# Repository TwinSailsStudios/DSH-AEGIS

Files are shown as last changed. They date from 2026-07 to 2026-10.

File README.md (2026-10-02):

# DSH-AEGIS


Image of PCB routing and tracing

image of schematic

Image of case + accessories (SD card case, micro sd card case, case cowl, stand, and sd/micro sd card storage)

Image of 3d model

https://github.com/user-attachments/assets/2e60c4a9-2eaf-4800-a794-9d0f289f58ca
Video of 3d model
### UPDATE NOTICE:
alr so i added step/stp files in the hardware folder in a zip file since they were too big for regular uploads (terminal limit is 100mb), i also made the pcb more compact, but the i didnt update the cover image, so you'll have to download the pcb file.

A physical password manager. ESP32-S3, a tiny OLED, six buttons, and an SD card.
Plugs into your computer over USB-C and *types* your passwords for you.

> **Status: designed, not built.** The schematic and PCB are done, the firmware
> is written. I haven't ordered the board yet because I'm paying for this stuff
> myself and PCBs cost money. Everything here is verified in KiCad, not on a
> bench. I'll update this when I can afford to fab it.

## why

I was using the same password on like nine different sites. Which is bad. Every
password manager I looked at wanted me to trust a company with all of it, and I
didn't love that either. So: keep them on an SD card, in my pocket, encrypted.

## what it does

- Locks behind a PIN you enter on the buttons
- Vault is encrypted on the SD card with AES-256
- Types the password straight into the login box over USB
- Can do username → Tab → password to fill a whole form
- Generates strong random passwords
- Auto-locks after 60s if you walk away

The typing thing is the whole point. The ESP32-S3 has **native USB**, so the board
doesn't *pretend* to be a keyboard — your computer genuinely thinks a keyboard got
plugged in. No drivers, no app. Works on any machine you walk up to.

## hardware

| part | what it does |
|---|---|
| ESP32-S3-WROOM-1 | the brain. picked for native USB |
| SSD1306 128x32 OLED | the screen (I2C) |
| 6x tactile switches | the controls |
| microSD module | where the vault lives (SPI) |
| USB-C receptacle | power + keyboard |
| AMS1117-3.3 | 5V → 3.3V |
| 2x 5.1K resistors | CC pins, so USB-C actually gives you power |

## pinout

| pin | goes to |
|---|---|
| IO0–IO5 | RECORD, SAVE, PLAY, SCROLL-L, SELECT, SCROLL-R |
| IO6 / IO7 | OLED SCL / SDA |
| IO35–IO38 | SD CS / MOSI / SCK / MISO |

**Heads up on IO35–37.** On an ESP32-S3 module with **octal (R8) PSRAM**, those
three pins are wired to the PSRAM die internally and you can't use them as GPIO.
This board only works with a **no-PSRAM or quad-PSRAM** module. If you build it,
check the part number, and set **PSRAM: Disabled** in the Arduino IDE — leave it
on OPI and the chip claims those pins at boot, before your code runs, and the SD
card silently never mounts.

## how you'd use it

Enter your PIN. Scroll to the login you want with the arrow buttons. Click into
whatever password box you're filling out on your computer. Hit **PLAY**. Done.

**SELECT** opens a menu with more options: type just the password, type
username+Tab+password, show the password on screen, or delete it.

Adding a new entry is the weak spot right now — you press **RECORD** and it hands
off to the serial monitor, where you send `label⇥username⇥password`. A password
manager that needs a computer to set up is a bit embarrassing and I want to fix
it. (Put `*` as the password and it generates one for you.)

Then hit **SAVE** to encrypt it and write it to the card.

## the crypto

Boring on purpose. Your PIN goes through PBKDF2-HMAC-SHA256 (60,000 rounds, random
salt) to turn 4 digits into a real key. Vault is AES-256-CBC. There's an HMAC over
the ciphertext, so a wrong PIN fails the check and the device never even attempts
to decrypt. Salt and IV are fresh every save.

I did not invent any of this. Inventing your own crypto is how you become a
cautionary example in someone's blog post.

## build it yourself

Firmware is in `firmware/`. You need the **U8g2** library; everything else ships
with the ESP32 Arduino core.

Board settings:
- Board: ESP32S3 Dev Module
- USB CDC On Boot: **Enabled**
- USB Mode: **USB-OTG (TinyUSB)**
- PSRAM: **Disabled** (see the IO35 warning above)

KiCad project is in `hardware/`.

## what's not done

- **Never physically built.** Simulated and verified in KiCad only.
- A 4-digit PIN is 10,000 combinations. The PBKDF2 rounds slow an attacker down a
  lot but it's not amazing if someone steals the card and is patient.
- No lockout after repeated wrong guesses.
- Can't add entries on the device, needs serial.
- No way to change your PIN without wiping everything.
- Case is modelled in Tinkercad but not printed.

## AI use
I used gemini to help with some kicad features and trying to debug a probelm with exporting my 3d model of my pcb
I used Claude to help write the firmware and to talk through design decisions
(pin conflicts, how to structure the vault encryption). The schematic, PCB layout, 
3D model, and this README are mine. the firmware, im not gonna act like i wrote it from scratch, it was more like using claude to frankenstien my code togetehr into a working firmware, since i haventbuilt ts irl yet, if any of yall try PLEASE lmk if theres any code problems, thx:)

EDIT: I also gave claude access to organize all the files

## license

MIT. do whatever.

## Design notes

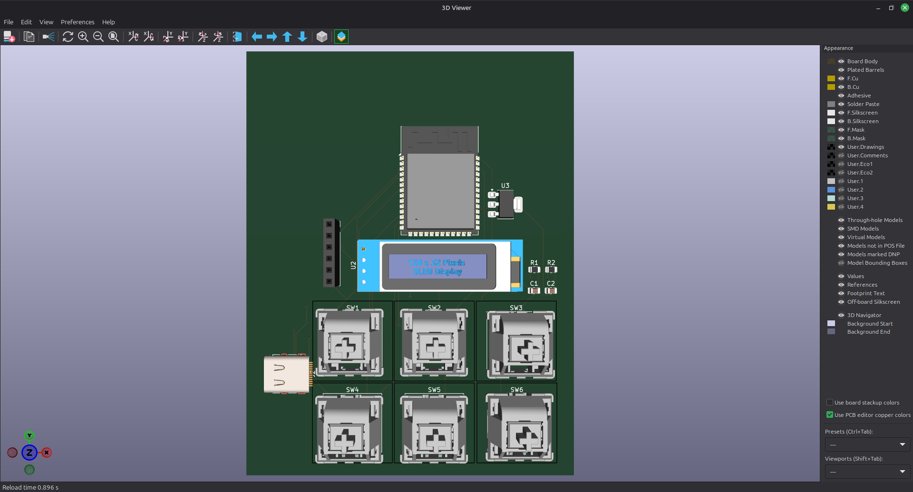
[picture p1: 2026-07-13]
assets/1783965913131_image.png

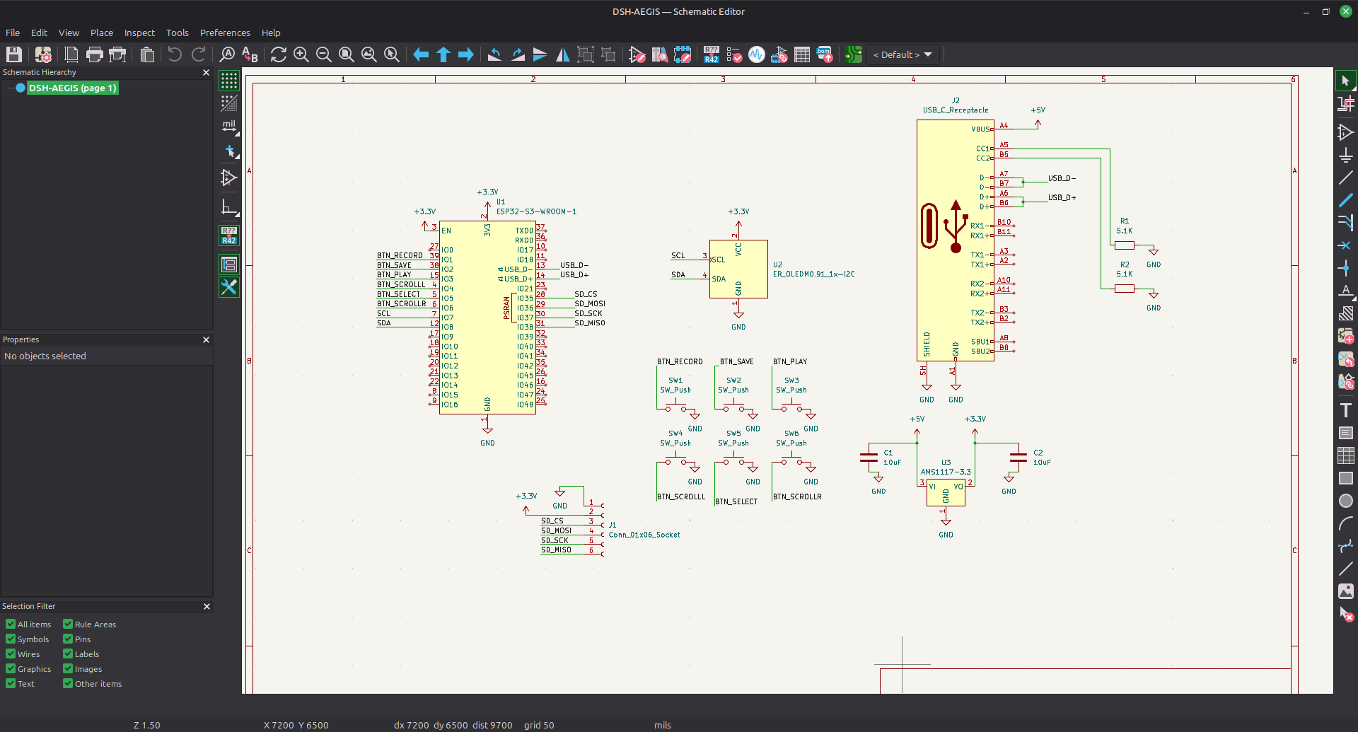
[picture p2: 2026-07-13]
assets/1783965924997_image.png

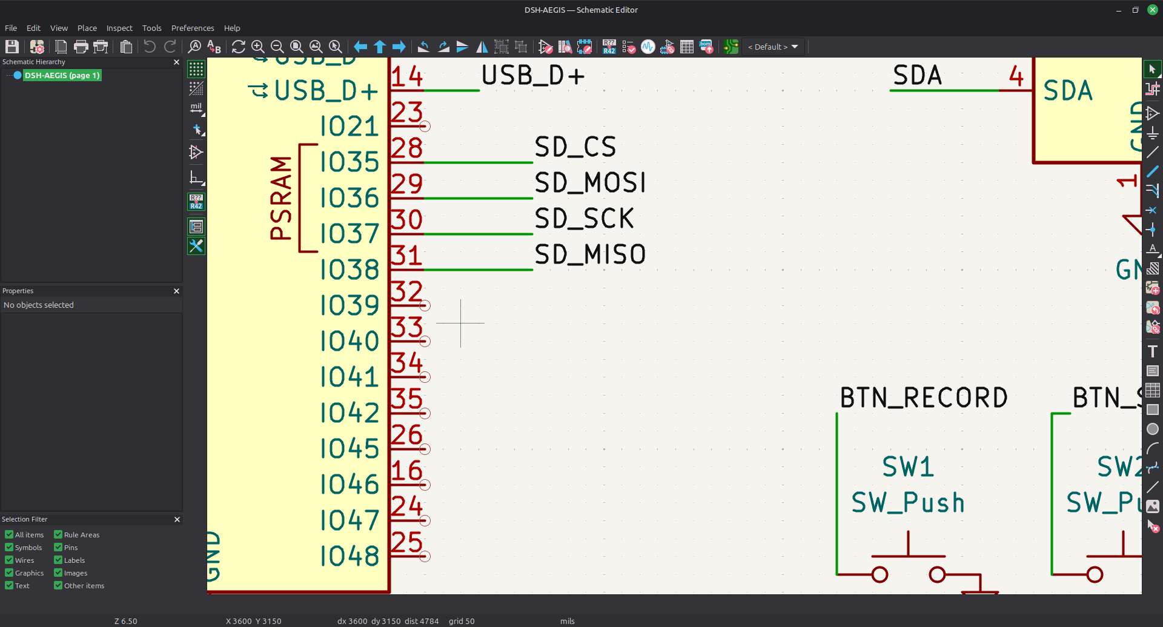
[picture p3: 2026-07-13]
assets/1783966510751_image.png

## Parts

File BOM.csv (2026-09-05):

Item / Component Name | Description / Purpose | Qty | Price (USD) | Total Cost (USD) | Buying Link
1x ESP32-S3-WROOM-1 (N16R8) | Main MCU module - WiFi/BLE USB HID drives OLED + SD vault | 1 | 3.40 | 3.40 | https://www.lcsc.com/product-detail/C2913202.html
1x 0.96" I2C OLED (SSD1306 4-pin) | 128x64 status/UI display I2C addr 0x3C | 1 | 17.50 | 17.50 | https://www.adafruit.com/product/326
1x AMS1117-3.3 (SOT-223) | 3.3V LDO regulator steps 5V USB rail to 3.3V | 1 | 0.10 | 0.10 | https://www.lcsc.com/product-detail/C6186.html
2x 10uF ceramic capacitor | LDO input/output bulk decoupling | 2 | 0.03 | 0.06 | https://www.lcsc.com/search?q=10uF%200603%2025V%20X7R
1x 1uF ceramic capacitor | EN-pin RC power-on delay | 1 | 0.02 | 0.02 | https://www.lcsc.com/search?q=1uF%200603%2050V%20X7R
1x USB-C Receptacle (16-pin) | USB 2.0 power + data TYPE-C-31-M-12 | 1 | 0.30 | 0.30 | https://www.lcsc.com/product-detail/C165948.html
1x 1x6 Pin Header Socket (2.54mm) | MicroSD SPI breakout connector | 1 | 0.15 | 0.15 | https://www.lcsc.com/search?q=female%20header%201x6%202.54mm
6x Cherry MX Keyswitch | Tactile push buttons MX1A-11NN | 6 | 1.25 | 7.50 | https://www.digikey.com/en/products/detail/cherry-americas-llc/MX1A-11NN/91136
2x 5.1k resistor | USB-C CC1/CC2 pulldowns UFP sink detection | 2 | 0.01 | 0.02 | https://www.lcsc.com/search?q=5.1k%200603%20resistor
1x 10k resistor | EN-pin pull-up | 1 | 0.01 | 0.01 | https://www.lcsc.com/search?q=10k%200603%20resistor
 |  |  | GRAND TOTAL | 29.06

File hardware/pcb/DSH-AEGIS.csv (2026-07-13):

Reference | Qty | Value | DNP | Exclude from BOM | Exclude from Board | Footprint | Datasheet
C1,C2 | 2 | 10uF |  |  |  | Capacitor_SMD:C_0805_2012Metric
J1 | 1 | Conn_01x06_Socket |  |  |  | Connector_PinSocket_2.54mm:PinSocket_1x06_P2.54mm_Vertical
J2 | 1 | USB_C_Receptacle |  |  |  | Connector_USB:USB_C_Receptacle_XKB_U262-16XN-4BVC11 | https://www.usb.org/sites/default/files/documents/usb_type-c.zip
R1,R2 | 2 | 5.1K |  |  |  | Resistor_SMD:R_0805_2012Metric
SW1,SW2,SW3,SW4,SW5,SW6 | 6 | SW_Push |  |  |  | Button_Switch_Keyboard:SW_Cherry_MX_1.00u_PCB
U1 | 1 | ESP32-S3-WROOM-1 |  |  |  | RF_Module:ESP32-S3-WROOM-1 | https://www.espressif.com/sites/default/files/documentation/esp32-s3-wroom-1_wroom-1u_datasheet_en.pdf
U2 | 1 | ER_OLEDM0.91_1x-I2C |  |  |  | Display:ER_OLEDM0.91_1x-I2C | https://www.buydisplay.com/download/manual/ER-OLEDM0.91-1_Datasheet.pdf
U3 | 1 | AMS1117-3.3 |  |  |  | Package_TO_SOT_SMD:SOT-223-3_TabPin2 | http://www.advanced-monolithic.com/pdf/ds1117.pdf

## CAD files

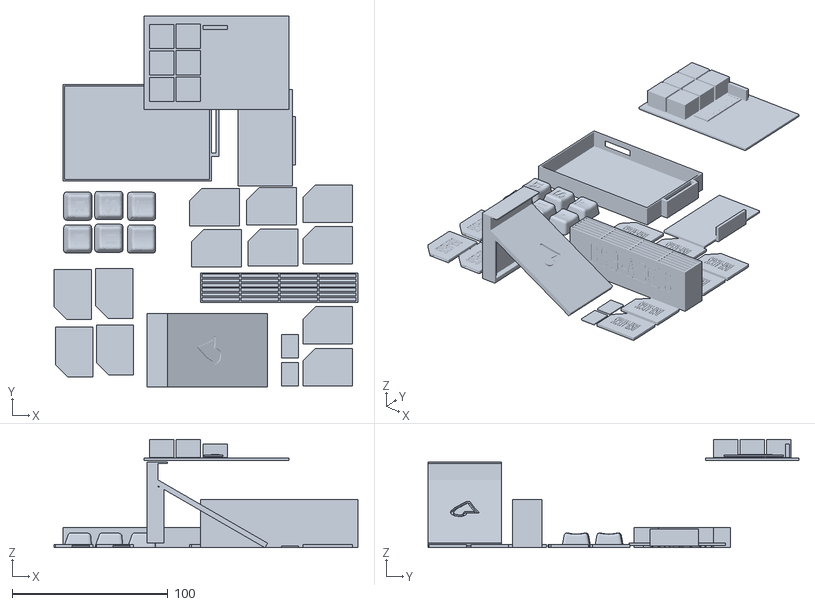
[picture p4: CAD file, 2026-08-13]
hardware/cad/DSH-AEGIS CASE VER 1.stl
194.8 x 238.0 x 69.6

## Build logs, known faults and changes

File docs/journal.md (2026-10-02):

---
title: "DSH-AEGIS"
author: "Pratik Dash (TwinSailsStudios)"
description: "A physical password manager. ESP32-S3, OLED, six buttons, SD card. Plugs in over USB-C and types your passwords for you."
created_at: "2026-06-24"
---

Quick note before anything: this is a design log, not a build log. I did the schematic, the PCB, the case, and the firmware, but I have not ordered the board. PCBs cost money and I'm paying for my own hobbies. So none of this has been flashed or tested on real hardware, it's all verified in KiCad, but it might not work if you do try to build it. HOLY IM SO DONE WITH MY LAPTOP, IT TURNED OFF WHILE I WAS ADDING MY LAPSE LINKS AND I LOST MY PROGROESS. IT DIDNT EVEN RUN OUTTA POWER.

# Day 1 - Starting the schematic - June 24th - 5 Hours

I've decided to build a physical password manager. Little handheld thing, screen, six buttons, SD card in the back, plugs into your computer over USB-C and types your passwords for you. I got tired of using the same password on like nine different sites which is objectively terrible.

I've done PCB stuff before but nothing with a chip this big, so this is a step up for me.

First thing I had to decide was the MCU, and I went with the ESP32-S3. The big reason is native USB. That means the board doesn't pretend to be a keyboard, your computer genuinely thinks a keyboard got plugged in. No drivers, no app, works on any machine you walk up to. If I used a normal ESP32 I'd need a whole separate USB chip and it gets uglier and more expensive.

Opened KiCad, dropped the S3 symbol in, and immediately felt out of my depth. This chip has an absurd number of pins. Spent most of today just reading the symbol figuring out which ones I'm even allowed to touch.

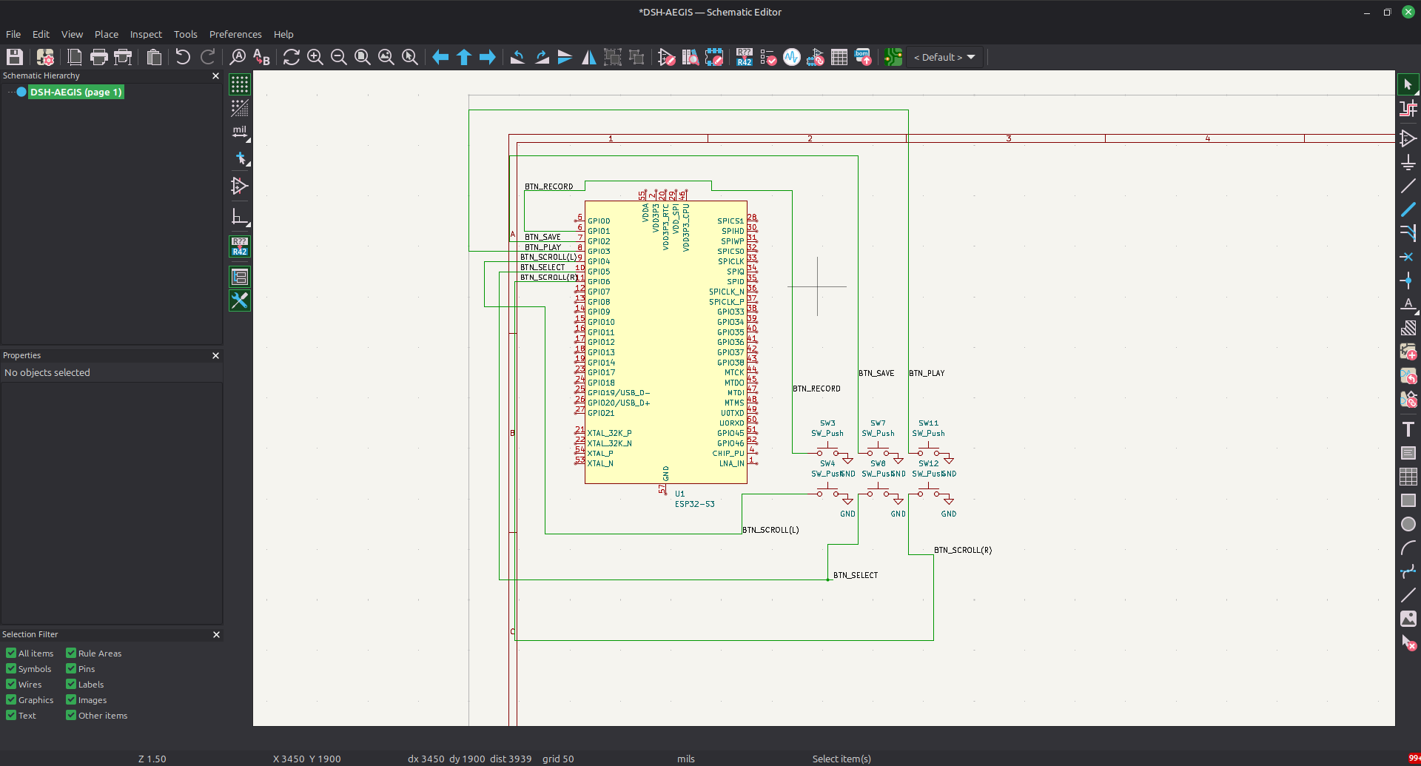
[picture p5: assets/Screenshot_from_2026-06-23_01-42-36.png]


Then I did the six buttons. RECORD, SAVE, PLAY, SCROLL LEFT, SELECT, SCROLL RIGHT. Each one is just a GPIO on one leg and ground on the other, that's it. No pull-up resistors needed because the ESP32 has them built in and I turn them on in software. Six fewer parts to buy.

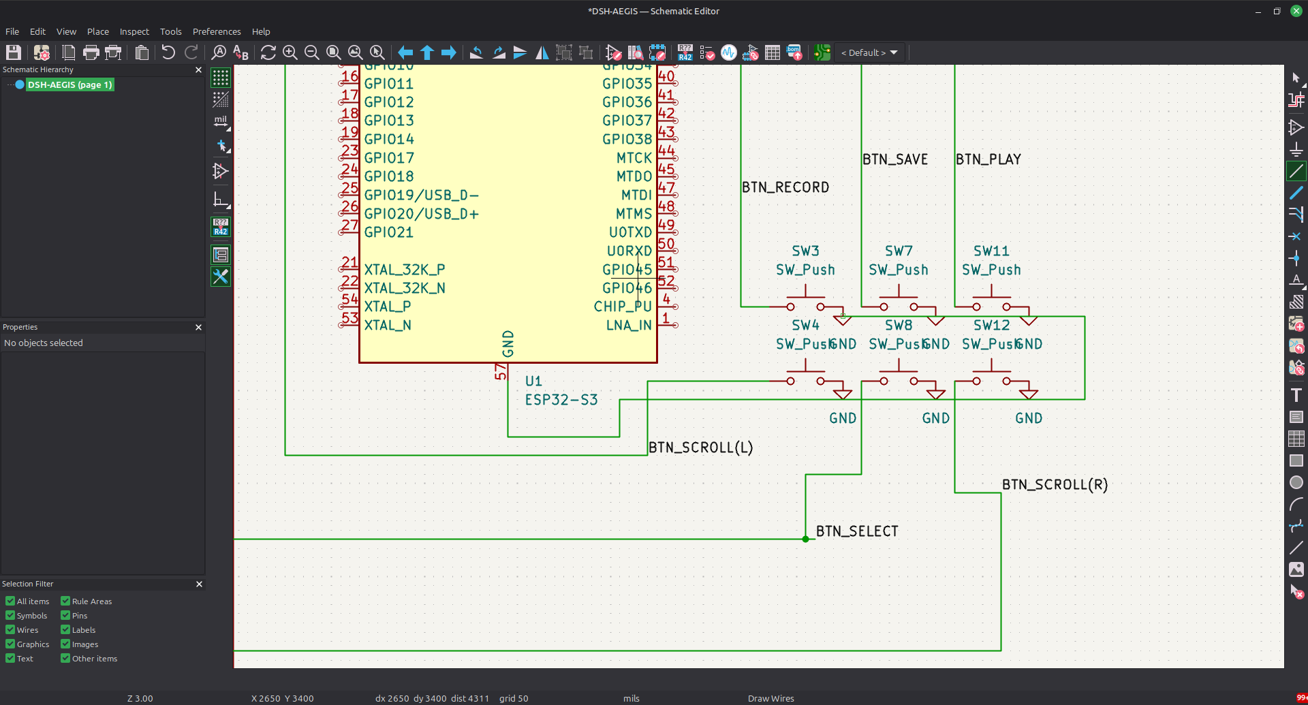
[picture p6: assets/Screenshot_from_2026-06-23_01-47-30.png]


The wires got messy but KiCad only cares that the connections are right, not that it looks nice.

Lapse: [yo MURDER my laptop]

**Total time spent: 5h**

# Day 2 - Rest of the schematic + footprints - June 25th - 6 Hours

Added everything else today:

* the OLED, which is I2C so only two wires, SCL and SDA
* the SD card socket, SPI, four wires
* USB-C receptacle
* AMS1117-3.3 to drop 5V down to 3.3V
* two 5.1K resistors on the CC pins

Those resistors are important and I almost didn't put them in. Without them the USB-C port has no way to tell your laptop "hey I'm a device, give me power" and the board just doesn't turn on. I only knew about this because I read like four forum threads of people asking why their USB-C board was dead and the answer was always the CC resistors.



Then footprints, which nobody warns you about. A schematic symbol is basically a cartoon, it doesn't know how big the real part actually is. So you have to go through every single component and tell KiCad which exact physical shape it is in real life.

15 components, one at a time, out of a list of 7,447 footprints.

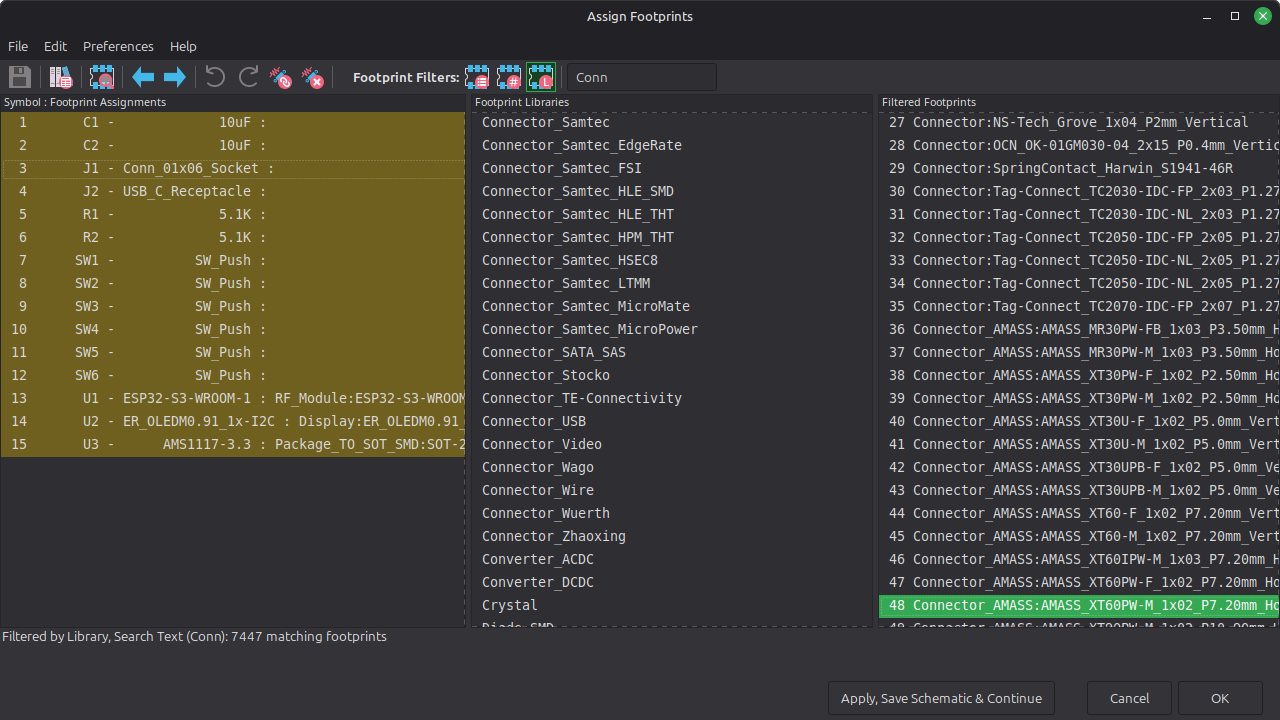
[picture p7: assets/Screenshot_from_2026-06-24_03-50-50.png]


I have now seen every connector ever manufactured.

Lapse: ["yeah add a lapse section, it'll be such a good idea!"]

**Total time spent: 6h**

# Day 3 - PCB layout, the long day - June 26th - 8 Hours

Biggest day by a mile. Today the schematic became an actual board.

When you first push everything into the PCB editor it just dumps all the parts in a pile with a horrifying spiderweb of white lines showing what needs to connect to what. It looks impossible. It's not, it just takes eight hours.

The layout I went with is six buttons in a 2x3 grid at the bottom like a keypad, OLED sitting right above them, ESP32 up top, USB-C on the left edge so the cable comes out the side instead of jabbing into your hand.

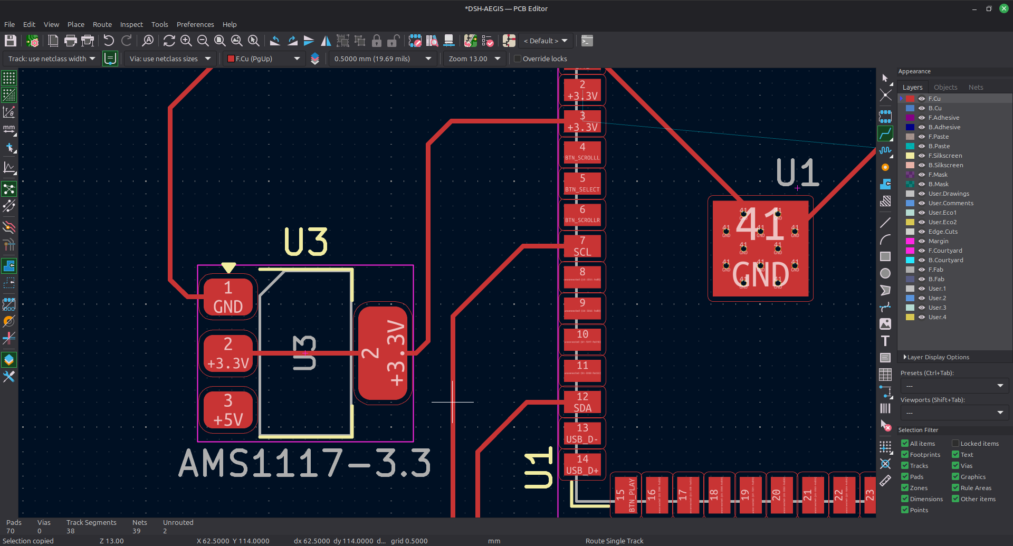
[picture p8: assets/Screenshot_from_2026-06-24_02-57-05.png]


Learned the annoying way that the ESP32 module has an antenna on it and you can't run copper underneath an antenna or the wifi gets worse. So there's this big hatched keep-out zone across the top of my board that I'm not allowed to route through. Had to redo a few traces once I realized.

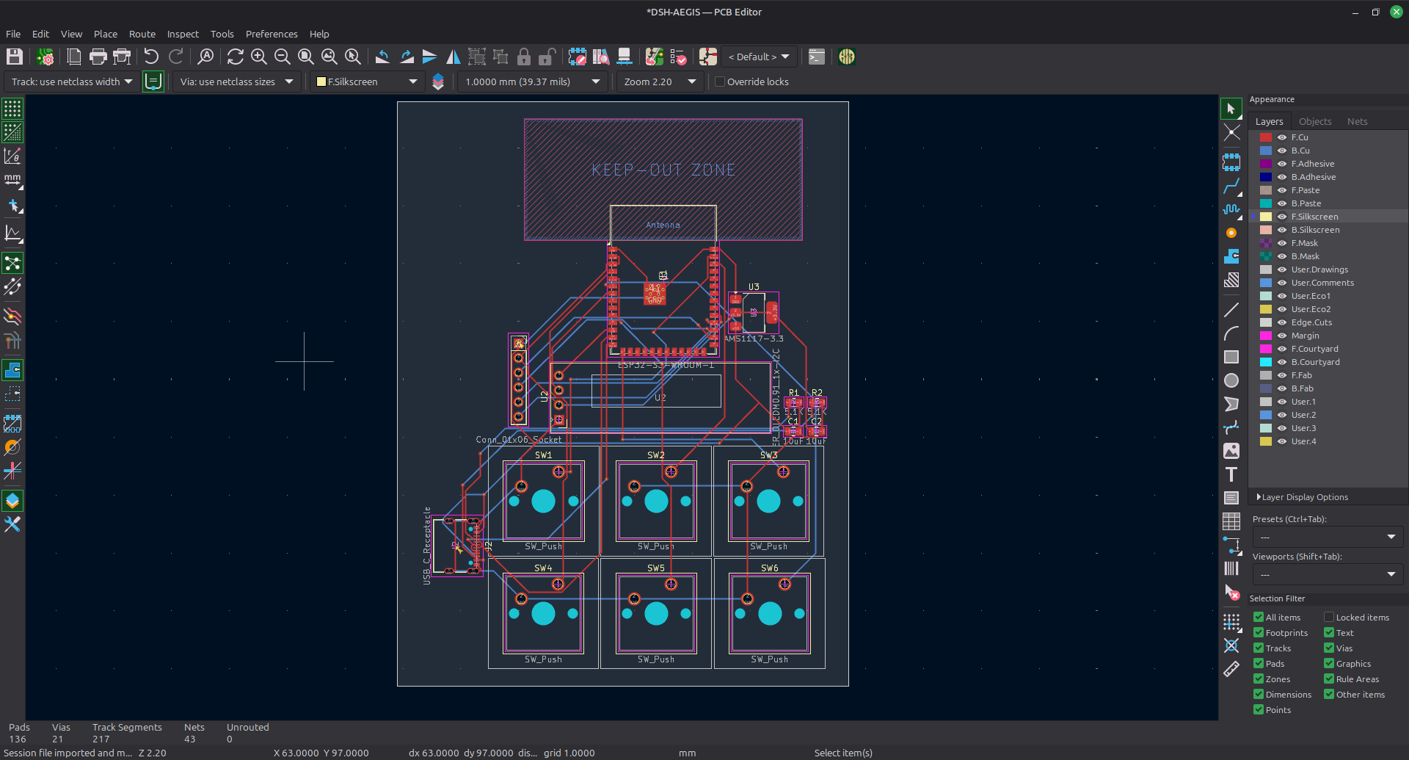
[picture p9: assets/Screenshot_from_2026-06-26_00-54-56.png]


Ended at 217 track segments, 21 vias, 43 nets, 0 unrouted. That last number is the one that actually matters and I looked at it for a while.

Did not move from this chair all day.

Lapse: [waaaaaaaaaaaaaaaaah]

**Total time spent: 8h**

# Day 4 - Silkscreen, and catching a pin conflict that would've cost me a board - June 27th - 4 Hours

Easy day mostly. Silkscreen is the white printing on a PCB and it costs literally nothing extra, the fab prints it either way, so obviously I put a heart on the back, my name, the project name, and some Kanye lyrics down the side.

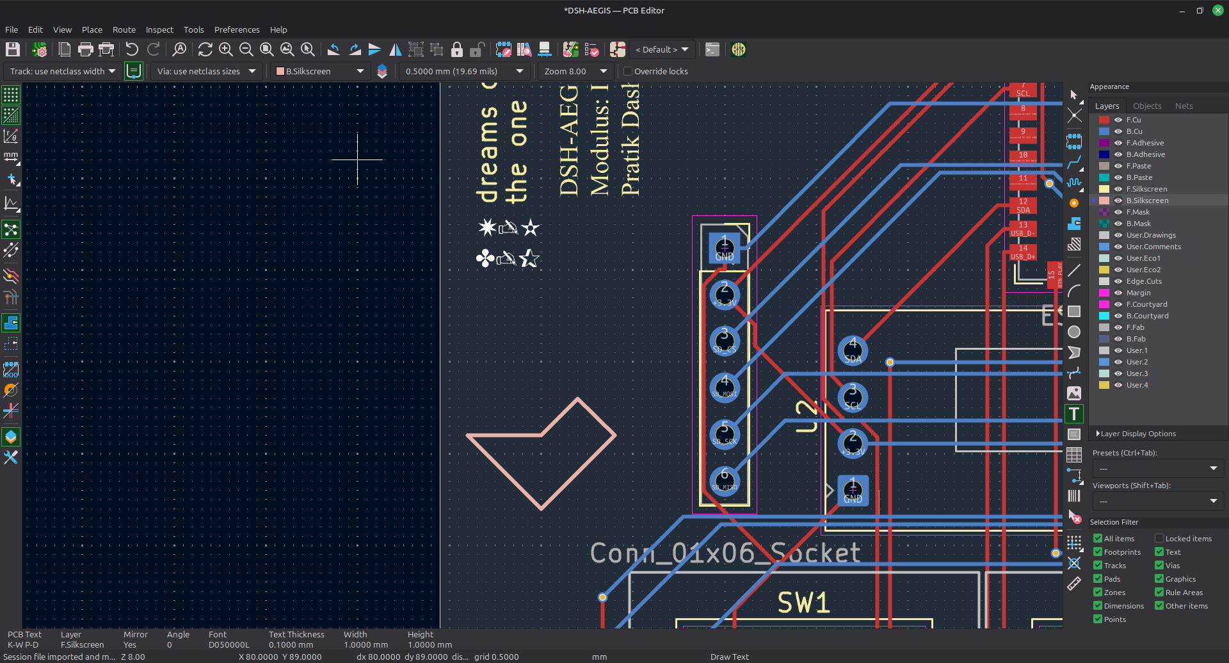
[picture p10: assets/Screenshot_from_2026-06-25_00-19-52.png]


Then while I was double checking my pin assignments against the datasheet before calling the board done, I found something that would've ruined the entire PCB order.

My SD card is on IO35, IO36, IO37 and IO38. On an ESP32-S3 module with octal (R8) PSRAM, IO35 through 37 are wired internally to the PSRAM chip. You physically cannot use them as GPIO. The KiCad symbol even brackets those three pins and literally labels them PSRAM, and I had been staring at that label for three days without it registering.

So this board only works with a module that has no PSRAM or quad PSRAM. And in the firmware, PSRAM has to be set to Disabled, because if the ESP32 thinks it has OPI PSRAM it grabs those pins at boot before my code even runs, and the SD card would just silently never mount.

I would have had zero clue why. I'd have gotten the board back, soldered the whole thing, and spent a weekend blaming my solder joints. Very glad I caught this on a screen and not on a desk. Put a big comment about it at the top of the firmware.

Then opened the 3D viewer to see what it'd look like when it's real, and honestly it looks like a product.

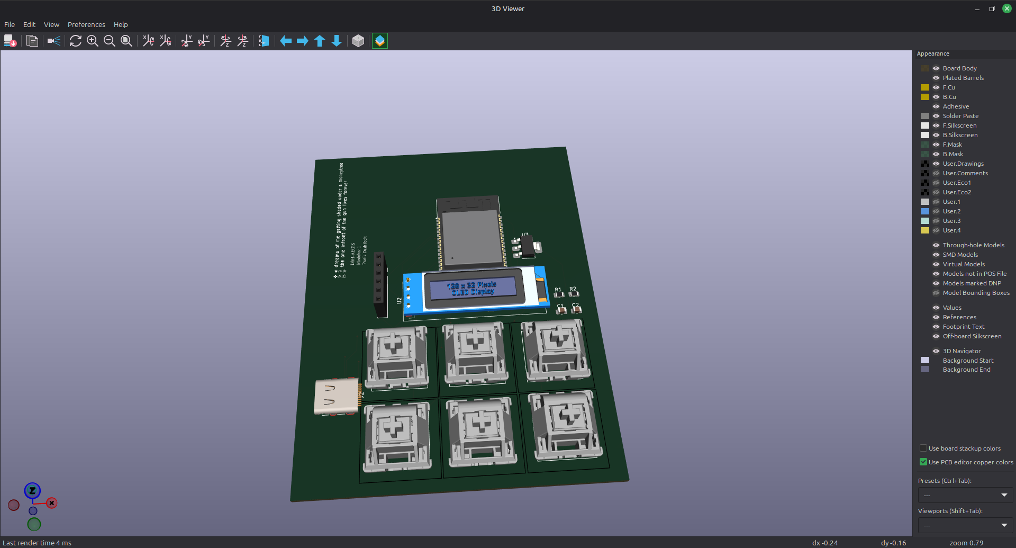
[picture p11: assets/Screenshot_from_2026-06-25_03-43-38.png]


Lapse: [TIMWANMNIHAC]

**Total time spent: 4h**

# Day 5 - Case in Tinkercad - June 28th - 5 Hours

A bare PCB in your pocket is a short circuit waiting to happen so it needs a case.

I used Tinkercad. I know. But I need a box with holes in it and Tinkercad makes a box with holes in it in fifteen minutes, and Fusion 360 makes me want to lie down. I'll learn Fusion eventually.

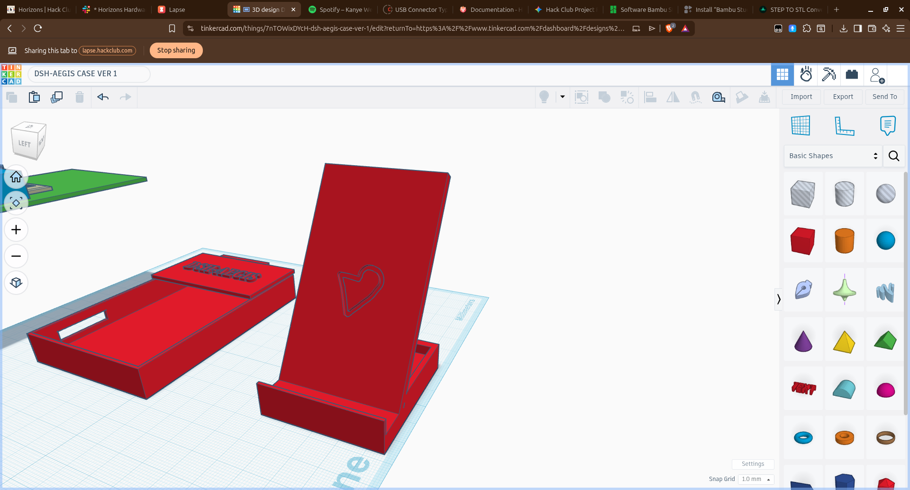
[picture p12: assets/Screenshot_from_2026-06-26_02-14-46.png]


Version 1 is a bottom tray the PCB drops into, a lid with a window cut out for the OLED, six button caps, a front piece with the heart on it, and cutouts for the USB-C port on the side and the SD card slot.

Then I laid everything out flat to check it'd actually print, and mostly to check the button caps weren't so tiny they'd fly off the print bed and disappear into the carpet forever.

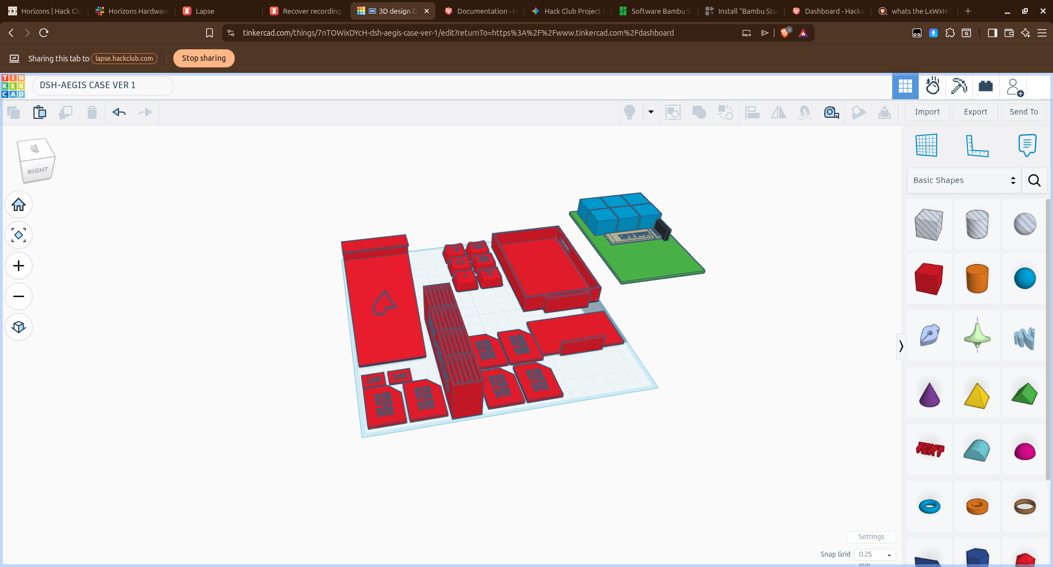
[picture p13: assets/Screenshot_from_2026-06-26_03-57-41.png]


Not printing it yet though. Every dimension in here is a guess off the KiCad model and I'd rather measure the real board with calipers than waste filament. So it stays a model.

Lapse: [payed the toll on a broken road]

**Total time spent: 5h**

# Day 6 - Firmware - June 30th - 6 Hours

Took a day off and then wrote the code. Used VS Code and the Arduino IDE, with the U8g2 library for the screen and mbedTLS for the crypto (both already come with the ESP32 core).

The flow is PIN screen, then unlock, then scroll through your saved logins, then hit PLAY and it types the password wherever your cursor is.

For the encryption I stuck to boring standard stuff on purpose. PBKDF2 stretches the 4 digit PIN into a real key, 60,000 rounds so guessing is slow. AES-256 for the vault itself. And an HMAC over the ciphertext, which means if you type the wrong PIN it fails a check and the device never even tries to decrypt anything. None of that is my invention. Making up your own crypto is how you end up as somebody's cautionary example.

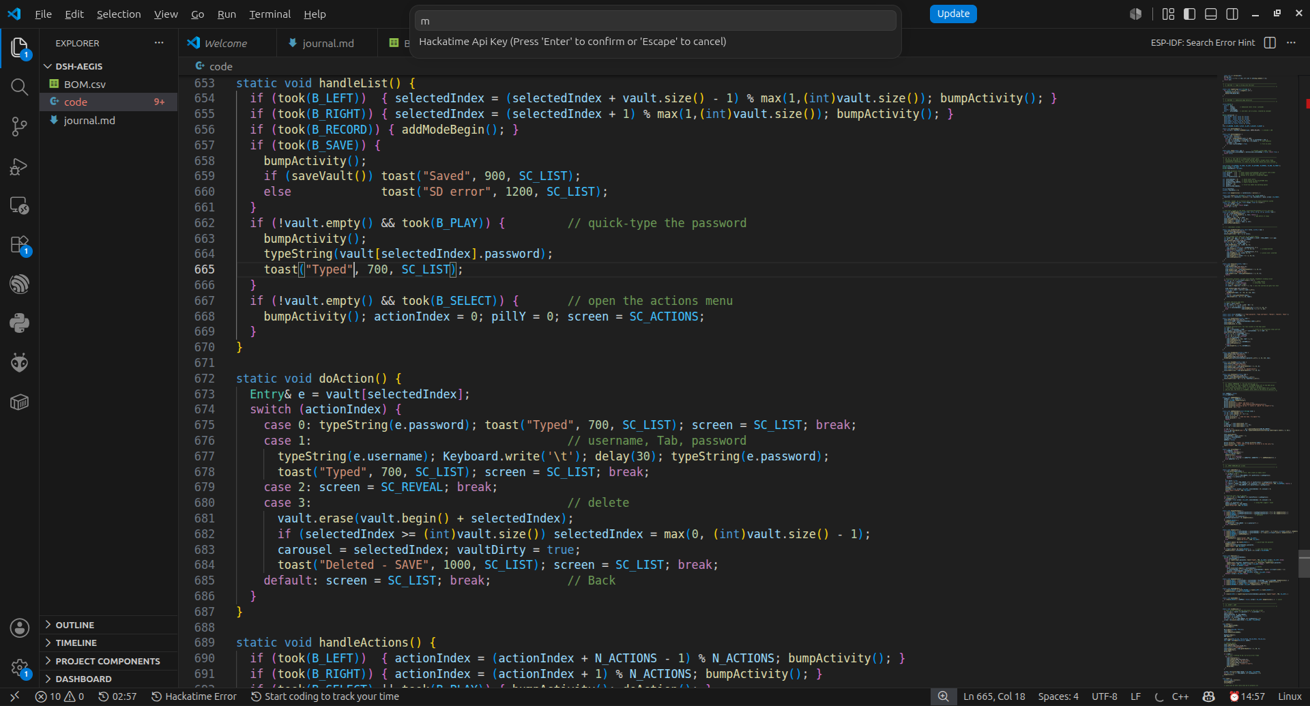
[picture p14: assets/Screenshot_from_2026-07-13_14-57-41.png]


The UI is the part I spent the most time on. Everything that moves, the carousel sliding between entries, the pill in the menus, the shake when you get the PIN wrong, is all one tiny function. It's just a number easing toward a target a little bit each frame. That's the entire animation system. Costs basically nothing and it makes a 128x32 monochrome screen feel like it actually has a UI instead of a menu.

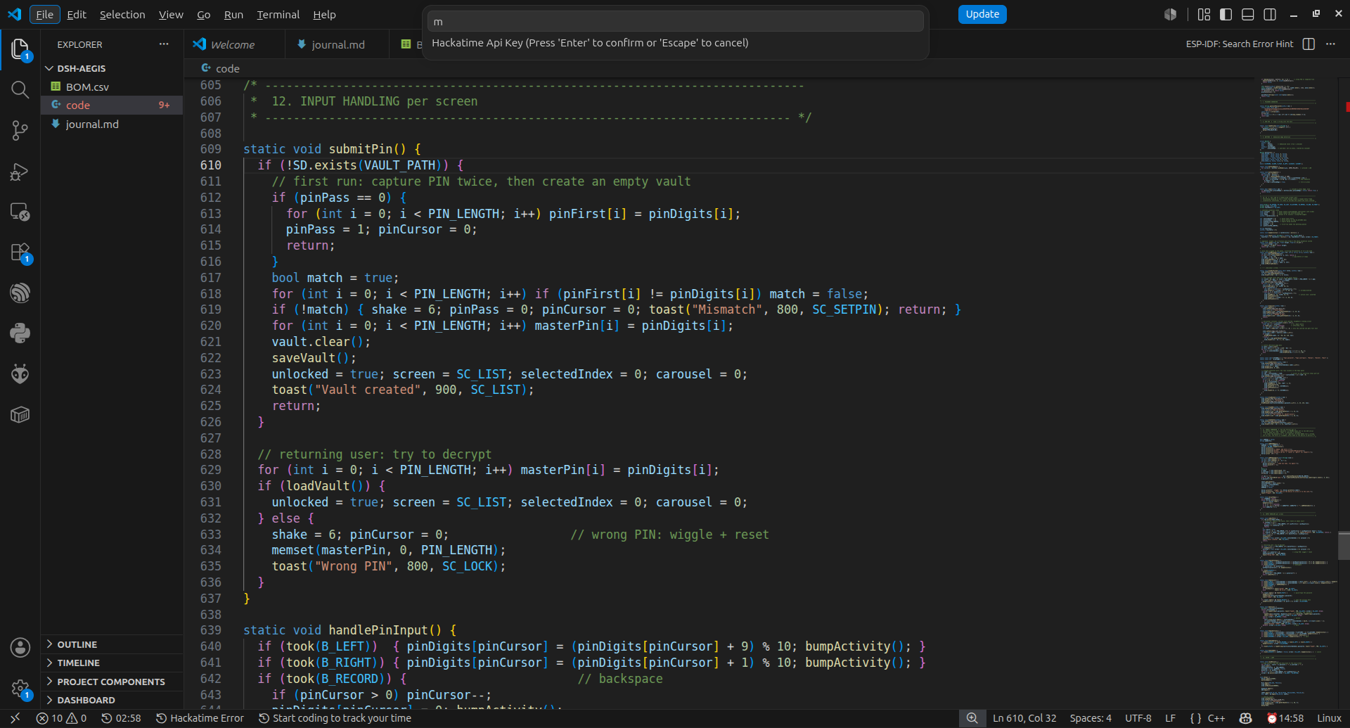
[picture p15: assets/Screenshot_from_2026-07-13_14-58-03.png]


The weak point is adding entries. Six buttons can't type a password, so RECORD hands off to the serial monitor and you send label, username, password separated by tabs. A password manager that needs a computer to set it up is a little embarrassing and it's the first thing I want to fix.

None of this has run on real hardware. It compiles and I've read through it a bunch of times but until I can afford the PCB it's all theoretical. I fully expect to find stuff wrong the second it actually boots.

Lapse: [i hate ts laptop dawg]

**Total time spent: 6h**

# Where it's at

Schematic done, board routed with 0 unrouted nets, case modelled, firmware written. Not built, because I'm funding this myself and the board plus components is real money I don't have right now. When I do have it, this becomes a build log.

Still want to do:

* add entries on the device instead of over serial
* PIN longer than 4 digits
* change your PIN without wiping the whole vault
* lockout after too many wrong guesses
* actually order the thing

**Grand total: 34h**

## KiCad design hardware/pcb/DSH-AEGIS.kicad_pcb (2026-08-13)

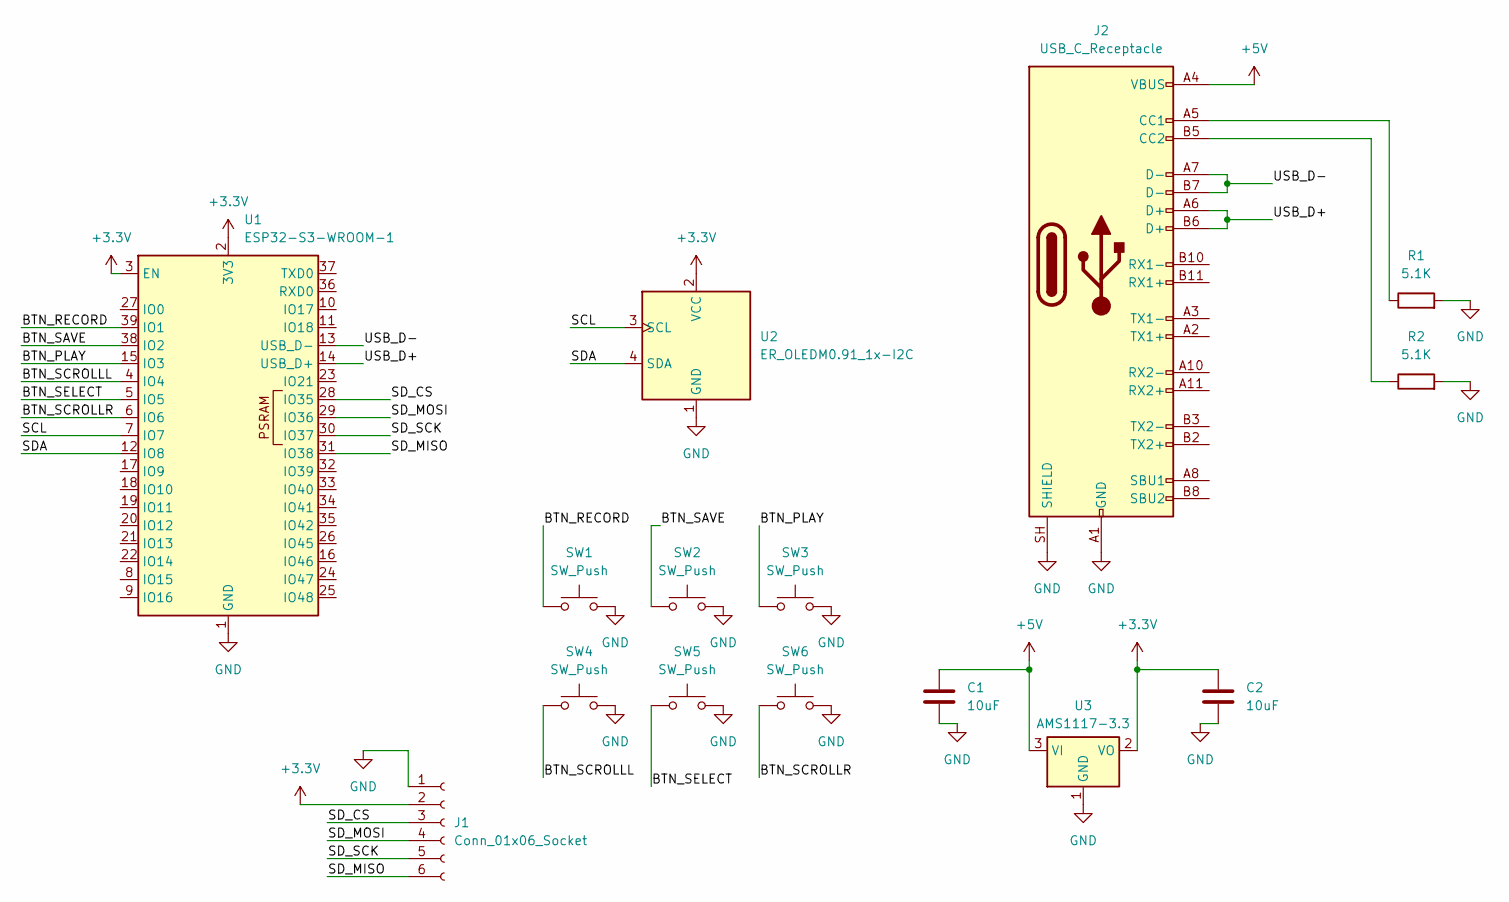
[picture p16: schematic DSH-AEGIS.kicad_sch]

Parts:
C1, C2: 10uF; C_0805_2012Metric
J1: Conn_01x06_Socket; PinSocket_1x06_P2.54mm_Vertical
J2: USB_C_Receptacle; USB_C_Receptacle_XKB_U262-16XN-4BVC11
R1, R2: 5.1K; R_0805_2012Metric
SW1, SW2, SW3, SW4, SW5, SW6: SW_Push; SW_Cherry_MX_1.00u_PCB
U1: ESP32-S3-WROOM-1
U2: ER_OLEDM0.91_1x-I2C
U3: AMS1117-3.3; SOT-223-3_TabPin2

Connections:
+3.3V: C2.1, J1.2, U1.2 (3V3), U1.3 (EN), U2.2 (VCC), U3.2 (VO)
+5V: C1.1, J2.A4 (VBUS), J2.A9 (VBUS), J2.B4 (VBUS), J2.B9 (VBUS), U3.3 (VI)
/BTN_PLAY: SW3.1, U1.15 (IO3)
/BTN_RECORD: SW1.1, U1.39 (IO1)
/BTN_SAVE: SW2.1, U1.38 (IO2)
/BTN_SCROLLL: SW4.1, U1.4 (IO4)
/BTN_SCROLLR: SW6.1, U1.6 (IO6)
/BTN_SELECT: SW5.1, U1.5 (IO5)
/SCL: U1.7 (IO7), U2.3 (SCL)
/SDA: U1.12 (IO8), U2.4 (SDA)
/SD_CS: J1.3, U1.28 (IO35)
/SD_MISO: J1.6, U1.31 (IO38)
/SD_MOSI: J1.4, U1.29 (IO36)
/SD_SCK: J1.5, U1.30 (IO37)
/USB_D+: J2.A6 (D+), J2.B6 (D+), U1.14 (USB_D+)
/USB_D-: J2.A7 (D-), J2.B7 (D-), U1.13 (USB_D-)
GND: C1.2, C2.2, J1.1, J2.A1 (GND), J2.A12 (GND), J2.B1 (GND), J2.B12 (GND), J2.SH (SHIELD), R1.2, R2.2, SW1.2, SW2.2, SW3.2, SW4.2, SW5.2, SW6.2, U1.1 (GND), U1.40 (GND), U1.41 (GND), U2.1 (GND), U3.1 (GND)
unnamed: J2.A5 (CC1), R1.1
unnamed: J2.B5 (CC2), R2.1

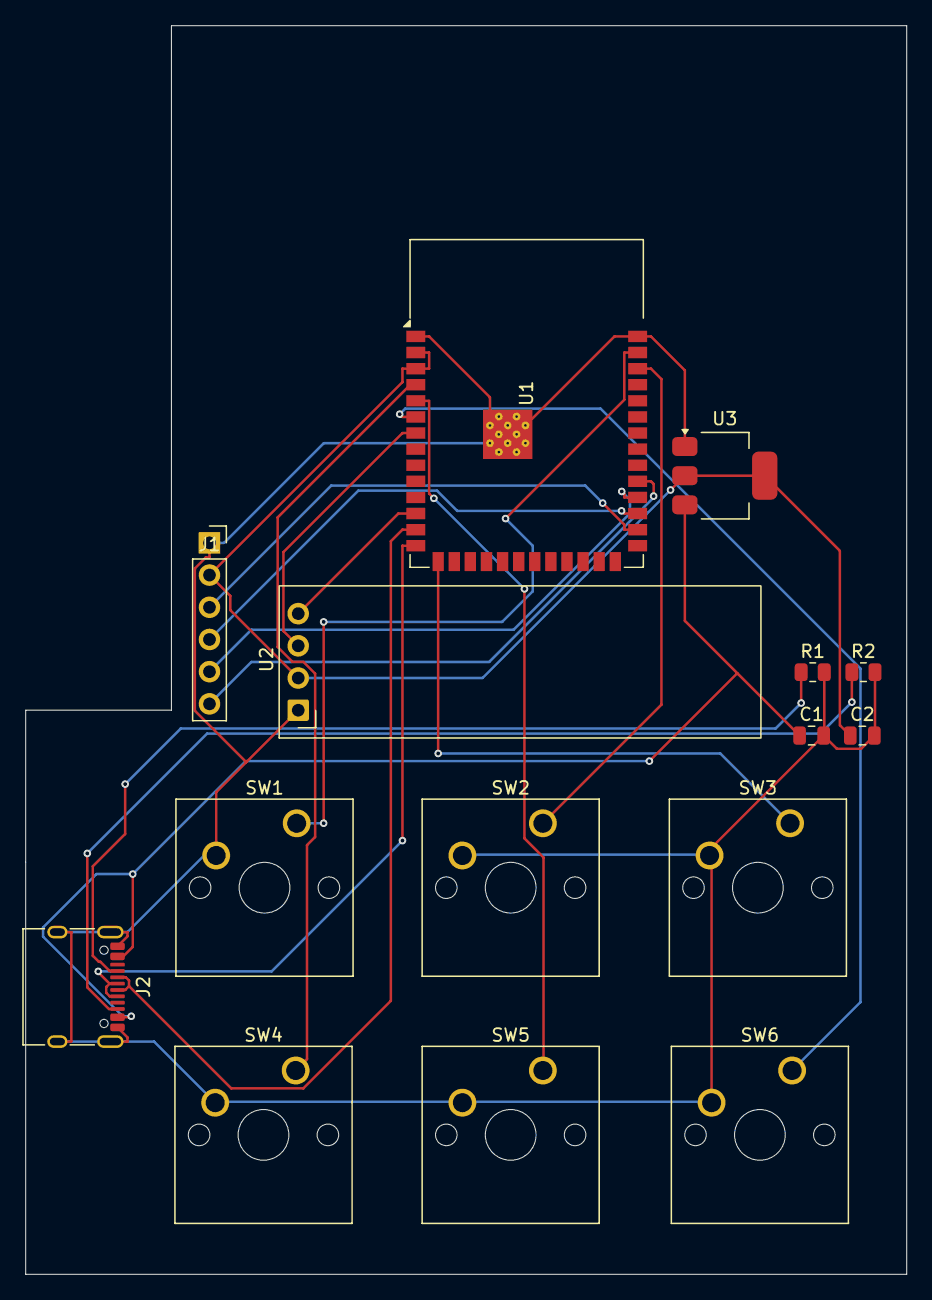
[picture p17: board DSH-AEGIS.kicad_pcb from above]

Board: 2 copper layers, 69.5 x 98.5 mm, 15 parts (0 on the bottom side), 19 nets.

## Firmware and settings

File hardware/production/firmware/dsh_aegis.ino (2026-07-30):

/* ============================================================================
 *  DSH-AEGIS  —  a physical password manager
 *  ----------------------------------------------------------------------------
 *  ESP32-S3-WROOM-1  •  128x32 SSD1306 OLED  •  6 buttons  •  SD card vault
 *  •  native USB-C HID keyboard
 *
 *  The idea: your passwords live encrypted on the SD card. You unlock the
 *  device with a PIN (entered on the buttons), scroll through your entries on
 *  the OLED, and when you hit PLAY the selected password gets *typed* into
 *  whatever field your computer's cursor is sitting in — because AEGIS shows
 *  up to the host as a plain USB keyboard. Nothing leaves the device except
 *  keystrokes.
 *
 *  Buttons (from the schematic):
 *     RECORD  IO0   start adding a new entry (over the USB serial console)
 *     SAVE    IO1   commit the vault to the SD card (encrypted)
 *     PLAY    IO2   type the selected entry
 *     SCROLL← IO3   previous
 *     SELECT  IO4   confirm / open
 *     SCROLL→ IO5   next
 *     (SCL IO6 / SDA IO7 -> OLED)
 *
 *  Arduino IDE board settings that matter:
 *     Board:            "ESP32S3 Dev Module"
 *     USB CDC On Boot:  Enabled
 *     USB Mode:         USB-OTG (TinyUSB)
 *     PSRAM:            Disabled   (or "QSPI PSRAM" if your part is an R2)
 *                       -- NOT "OPI PSRAM": that would claim IO35-37, which the
 *                          SD card is using on this board.
 *
 *  Libraries: U8g2 (OLED), plus the SD/SPI/USB stuff that ships with the
 *  ESP32 Arduino core. Crypto is mbedTLS, also already in the core.
 * ========================================================================== */

#include <Wire.h>
#include <SPI.h>
#include <SD.h>
#include <U8g2lib.h>
#include <vector>

#include "USB.h"
#include "USBHIDKeyboard.h"

#include "mbedtls/aes.h"
#include "mbedtls/md.h"
#include "esp_random.h"

#include "dsh_icons.h"   // boot logo + Flipper-style pixel icons

/* ----------------------------------------------------------------------------
 *  1. WIRING  —  the only part you should need to touch
 * -------------------------------------------------------------------------- */

// Buttons + I2C: these I read straight off your schematic.
#define PIN_RECORD   0
#define PIN_SAVE     1
#define PIN_PLAY     2
#define PIN_SCROLL_L 3
#define PIN_SELECT   4
#define PIN_SCROLL_R 5
#define PIN_SCL      6
#define PIN_SDA      7

// SD card (SPI), straight off the schematic.
// Note: the symbol brackets IO35-37 as "PSRAM" because on an *R8* (octal PSRAM)
// module those pins are wired to the PSRAM die and are unusable. This build
// targets a module with no PSRAM / quad PSRAM, where they're free GPIO. If you
// ever swap in an R8 part, these three have to move.
#define PIN_SD_CS    35
#define PIN_SD_MOSI  36
#define PIN_SD_SCK   37
#define PIN_SD_MISO  38

/* ----------------------------------------------------------------------------
 *  2. FEEL  —  knobs for behaviour, tune to taste
 * -------------------------------------------------------------------------- */

static const char*    VAULT_PATH     = "/AEGIS.VAULT";
static const char*    SETTINGS_PATH  = "/AEGIS.CFG";   // non-secret prefs
static const uint8_t  PIN_LENGTH     = 4;        // digits in the master PIN
static const uint32_t KDF_ITERATIONS = 60000;    // PBKDF2 rounds (unlock cost)

// These start at sensible defaults but are editable in the Settings screen and
// saved to SD, so they survive a reboot. Compile-time constants can't be
// changed at runtime, so they live as plain variables instead.
static uint32_t idleLockMs   = 60000;   // auto-lock after inactivity (0 = never)
static uint8_t  typeDelayMs  = 6;       // per-keystroke delay, HID reliability
static uint8_t  genPwLength  = 20;      // default generated-password length
static bool     typeEnter    = false;   // press Enter after typing a password?

/* ----------------------------------------------------------------------------
 *  3. HARDWARE OBJECTS
 * -------------------------------------------------------------------------- */

// Full-frame buffer so we can animate freely (U8g2 clips off-screen draws).
U8G2_SSD1306_128X32_UNIVISION_F_HW_I2C oled(U8G2_R0, U8X8_PIN_NONE);
USBHIDKeyboard Keyboard;
SPIClass sdSPI(FSPI);

/* ----------------------------------------------------------------------------
 *  4. THE VAULT
 * -------------------------------------------------------------------------- */

struct Entry {
  String label;      // "GitHub"
  String username;   // "pratik@…"
  String password;   // the secret
};

std::vector<Entry> vault;
uint8_t  masterPin[PIN_LENGTH];    // held in RAM only while unlocked
bool     vaultDirty = false;       // true = unsaved changes, nudge the SAVE btn
bool     unlocked   = false;

/* ----------------------------------------------------------------------------
 *  5. CRYPTO
 *  PBKDF2-HMAC-SHA256 stretches the PIN into a key; AES-256-CBC encrypts the
 *  vault; an HMAC over the ciphertext lets us reject a wrong PIN (or tampering)
 *  before we ever try to decrypt. Small, boring, and correct — the good kind.
 * -------------------------------------------------------------------------- */

static void hmacSha256(const uint8_t* key, size_t klen,
                       const uint8_t* msg, size_t mlen, uint8_t* out /*32*/) {
  mbedtls_md_context_t ctx;
  mbedtls_md_init(&ctx);
  mbedtls_md_setup(&ctx, mbedtls_md_info_from_type(MBEDTLS_MD_SHA256), 1);
  mbedtls_md_hmac_starts(&ctx, key, klen);
  mbedtls_md_hmac_update(&ctx, msg, mlen);
  mbedtls_md_hmac_finish(&ctx, out);
  mbedtls_md_free(&ctx);
}

// Rolled by hand so it works the same on every core version.
static void pbkdf2(const uint8_t* pw, size_t pwlen,
                   const uint8_t* salt, size_t slen,
                   uint32_t iters, uint8_t* out, size_t outlen) {
  uint32_t blocks = (outlen + 31) / 32;
  uint8_t  U[32], T[32], block[64];
  for (uint32_t i = 1; i <= blocks; i++) {
    memcpy(block, salt, slen);
    block[slen + 0] = (i >> 24) & 0xff;
    block[slen + 1] = (i >> 16) & 0xff;
    block[slen + 2] = (i >>  8) & 0xff;
    block[slen + 3] =  i        & 0xff;
    hmacSha256(pw, pwlen, block, slen + 4, U);
    memcpy(T, U, 32);
    for (uint32_t j = 1; j < iters; j++) {
      hmacSha256(pw, pwlen, U, 32, U);
      for (int k = 0; k < 32; k++) T[k] ^= U[k];
    }
    size_t off = (i - 1) * 32;
    size_t n   = (outlen - off < 32) ? (outlen - off) : 32;
    memcpy(out + off, T, n);
  }
}

static void randomBytes(uint8_t* buf, size_t n) {
  for (size_t i = 0; i < n; i++) buf[i] = (uint8_t)(esp_random() & 0xff);
}

// PKCS#7 pad -> AES-256-CBC. `out` must have room for the padded length.
static size_t aesEncrypt(const uint8_t* key, const uint8_t* iv,
                         const uint8_t* in, size_t inLen, uint8_t* out) {
  size_t pad     = 16 - (inLen % 16);          // 1..16, always adds a block if aligned
  size_t total   = inLen + pad;
  memcpy(out, in, inLen);
  for (size_t i = 0; i < pad; i++) out[inLen + i] = (uint8_t)pad;

  uint8_t ivCopy[16];  memcpy(ivCopy, iv, 16);  // CBC mutates the IV
  mbedtls_aes_context aes; mbedtls_aes_init(&aes);
  mbedtls_aes_setkey_enc(&aes, key, 256);
  mbedtls_aes_crypt_cbc(&aes, MBEDTLS_AES_ENCRYPT, total, ivCopy, out, out);
  mbedtls_aes_free(&aes);
  return total;
}

// Returns plaintext length, or 0 if the padding is nonsense.
static size_t aesDecrypt(const uint8_t* key, const uint8_t* iv,
                         const uint8_t* in, size_t inLen, uint8_t* out) {
  if (inLen == 0 || inLen % 16) return 0;
  uint8_t ivCopy[16]; memcpy(ivCopy, iv, 16);
  mbedtls_aes_context aes; mbedtls_aes_init(&aes);
  mbedtls_aes_setkey_dec(&aes, key, 256);
  mbedtls_aes_crypt_cbc(&aes, MBEDTLS_AES_DECRYPT, inLen, ivCopy, in, out);
  mbedtls_aes_free(&aes);

  uint8_t pad = out[inLen - 1];
  if (pad == 0 || pad > 16) return 0;
  for (uint8_t i = 0; i < pad; i++)          // constant-ish padding check
    if (out[inLen - 1 - i] != pad) return 0;
  return inLen - pad;
}

/* ----------------------------------------------------------------------------
 *  6. SERIALISE  <->  DISK
 *  On the wire the vault is just tab-separated lines: label \t user \t pass.
 *  We forbid tabs/newlines inside fields, so parsing stays trivial.
 * -------------------------------------------------------------------------- */

static String serializeVault() {
  String s;
  for (auto& e : vault) {
    s += e.label; s += '\t';
    s += e.username; s += '\t';
    s += e.password; s += '\n';
  }
  return s;
}

static void parseVault(const String& plain) {
  vault.clear();
  int start = 0;
  while (start < (int)plain.length()) {
    int nl = plain.indexOf('\n', start);
    if (nl < 0) nl = plain.length();
    String line = plain.substring(start, nl);
    start = nl + 1;
    if (line.length() == 0) continue;

    int t1 = line.indexOf('\t');
    int t2 = line.indexOf('\t', t1 + 1);
    if (t1 < 0 || t2 < 0) continue;
    Entry e;
    e.label    = line.substring(0, t1);
    e.username = line.substring(t1 + 1, t2);
    e.password = line.substring(t2 + 1);
    vault.push_back(e);
  }
}

// File layout: "AEGIS1" | salt[16] | iv[16] | u32 cipherLen | cipher | mac[32]
static bool saveVault() {
  uint8_t salt[16], iv[16], keyMaterial[64];
  randomBytes(salt, 16);
  randomBytes(iv, 16);
  pbkdf2(masterPin, PIN_LENGTH, salt, 16, KDF_ITERATIONS, keyMaterial, 64);
  const uint8_t* encKey = keyMaterial;       // first 32 bytes
  const uint8_t* macKey = keyMaterial + 32;  // next  32 bytes

  String plain = serializeVault();
  std::vector<uint8_t> cipher(plain.length() + 16);
  size_t cipherLen = aesEncrypt(encKey, iv,
                                (const uint8_t*)plain.c_str(),
                                plain.length(), cipher.data());

  // MAC covers salt+iv+len+cipher so nothing can be swapped around underneath us.
  std::vector<uint8_t> macIn;
  macIn.insert(macIn.end(), salt, salt + 16);
  macIn.insert(macIn.end(), iv, iv + 16);
  uint32_t clen = cipherLen;
  macIn.push_back(clen & 0xff);       macIn.push_back((clen >> 8) & 0xff);
  macIn.push_back((clen >> 16)&0xff); macIn.push_back((clen >> 24)& 0xff);
  macIn.insert(macIn.end(), cipher.begin(), cipher.begin() + cipherLen);
  uint8_t mac[32];
  hmacSha256(macKey, 32, macIn.data(), macIn.size(), mac);

  SD.remove(VAULT_PATH);
  File f = SD.open(VAULT_PATH, FILE_WRITE);
  if (!f) return false;
  f.write((const uint8_t*)"AEGIS1", 6);
  f.write(salt, 16);
  f.write(iv, 16);
  f.write((uint8_t*)&clen, 4);
  f.write(cipher.data(), cipherLen);
  f.write(mac, 32);
  f.close();

  memset(keyMaterial, 0, sizeof(keyMaterial));  // don't leave keys lying around
  vaultDirty = false;
  return true;
}

// Tries to unlock with the PIN currently in masterPin[]. Returns false on a
// bad PIN (or a corrupt/absent file) without leaking which.
static bool loadVault() {
  File f = SD.open(VAULT_PATH, FILE_READ);
  if (!f) return false;

  char magic[6];
  if (f.read((uint8_t*)magic, 6) != 6 || memcmp(magic, "AEGIS1", 6)) { f.close(); return false; }
  uint8_t salt[16], iv[16]; uint32_t clen = 0;
  f.read(salt, 16); f.read(iv, 16); f.read((uint8_t*)&clen, 4);
  if (clen == 0 || clen > 65536) { f.close(); return false; }

  std::vector<uint8_t> cipher(clen);
  if (f.read(cipher.data(), clen) != (int)clen) { f.close(); return false; }
  uint8_t macFile[32];
  if (f.read(macFile, 32) != 32) { f.close(); return false; }
  f.close();

  uint8_t keyMaterial[64];
  pbkdf2(masterPin, PIN_LENGTH, salt, 16, KDF_ITERATIONS, keyMaterial, 64);
  const uint8_t* encKey = keyMaterial;
  const uint8_t* macKey = keyMaterial + 32;

  std::vector<uint8_t> macIn;
  macIn.insert(macIn.end(), salt, salt + 16);
  macIn.insert(macIn.end(), iv, iv + 16);
  macIn.push_back(clen & 0xff);        macIn.push_back((clen >> 8) & 0xff);
  macIn.push_back((clen >> 16) & 0xff); macIn.push_back((clen >> 24) & 0xff);
  macIn.insert(macIn.end(), cipher.begin(), cipher.end());
  uint8_t macCalc[32];
  hmacSha256(macKey, 32, macIn.data(), macIn.size(), macCalc);

  if (memcmp(macCalc, macFile, 32) != 0) {      // wrong PIN or tampered file
    memset(keyMaterial, 0, sizeof(keyMaterial));
    return false;
  }

  std::vector<uint8_t> plain(clen + 1, 0);
  size_t plainLen = aesDecrypt(encKey, iv, cipher.data(), clen, plain.data());
  memset(keyMaterial, 0, sizeof(keyMaterial));
  if (plainLen == 0) return false;
  plain[plainLen] = 0;

  parseVault(String((const char*)plain.data()));
  return true;
}

/* ----------------------------------------------------------------------------
 *  7. PASSWORD GENERATOR
 * -------------------------------------------------------------------------- */

static String generatePassword(uint8_t len) {
  static const char* set =
      "abcdefghijklmnopqrstuvwxyzABCDEFGHIJKLMNOPQRSTUVWXYZ0123456789"
      "!@#$%^&*()-_=+[]{}";
  const int n = strlen(set);
  String out;
  for (uint8_t i = 0; i < len; i++) out += set[esp_random() % n];
  return out;
}

/* ----------------------------------------------------------------------------
 *  7b. SETTINGS  —  non-secret prefs, saved as a plain little file on the card
 * -------------------------------------------------------------------------- */

static void saveSettings() {
  SD.remove(SETTINGS_PATH);
  File f = SD.open(SETTINGS_PATH, FILE_WRITE);
  if (!f) return;
  f.printf("idle=%lu\n", (unsigned long)idleLockMs);
  f.printf("typedelay=%u\n", typeDelayMs);
  f.printf("genlen=%u\n", genPwLength);
  f.printf("enter=%u\n", typeEnter ? 1 : 0);
  f.close();
}

static void loadSettings() {
  File f = SD.open(SETTINGS_PATH, FILE_READ);
  if (!f) return;                       // no file yet: keep the defaults
  while (f.available()) {
    String line = f.readStringUntil('\n');
    int eq = line.indexOf('=');
    if (eq < 0) continue;
    String k = line.substring(0, eq);
    long   v = line.substring(eq + 1).toInt();
    if      (k == "idle")      idleLockMs  = (uint32_t)v;
    else if (k == "typedelay") typeDelayMs = constrain((int)v, 0, 50);
    else if (k == "genlen")    genPwLength = constrain((int)v, 8, 64);
    else if (k == "enter")     typeEnter   = (v != 0);
  }
  f.close();
}

/* ----------------------------------------------------------------------------
 *  8. USB HID  —  type a string into the host
 * -------------------------------------------------------------------------- */

static void typeString(const String& s) {
  for (size_t i = 0; i < s.length(); i++) {
    Keyboard.write(s[i]);
    delay(typeDelayMs);
  }
}

/* ----------------------------------------------------------------------------
 *  9. BUTTONS  —  debounced edge detection
 * -------------------------------------------------------------------------- */

struct Button {
  uint8_t  pin;
  bool     stable;       // debounced level (true = pressed)
  bool     lastRaw;
  uint32_t lastChange;
  bool     pressedEdge;  // one-shot: set on press, cleared by consumer
};

Button buttons[6] = {
  {PIN_RECORD, false, false, 0, false},
  {PIN_SAVE,   false, false, 0, false},
  {PIN_PLAY,   false, false, 0, false},
  {PIN_SCROLL_L, false, false, 0, false},
  {PIN_SELECT, false, false, 0, false},
  {PIN_SCROLL_R, false, false, 0, false},
};
enum { B_RECORD, B_SAVE, B_PLAY, B_LEFT, B_SELECT, B_RIGHT };

static void buttonsBegin() {
  for (auto& b : buttons) pinMode(b.pin, INPUT_PULLUP);  // pressed = LOW
}

static void buttonsUpdate() {
  uint32_t now = millis();
  for (auto& b : buttons) {
    bool raw = (digitalRead(b.pin) == LOW);
    if (raw != b.lastRaw) { b.lastRaw = raw; b.lastChange = now; }
    if (now - b.lastChange > 25 && raw != b.stable) {  // 25ms debounce
      b.stable = raw;
      if (raw) b.pressedEdge = true;                   // fire on press
    }
  }
}

static bool took(uint8_t idx) {           // consume a press edge, once
  if (buttons[idx].pressedEdge) { buttons[idx].pressedEdge = false; return true; }
  return false;
}

/* ----------------------------------------------------------------------------
 *  10. UI  —  the "iOS on a stamp-sized screen" part
 *  Everything animated is just a float easing toward a target every frame
 *  (exponential smoothing). It reads as springy and liquid and costs nothing.
 * -------------------------------------------------------------------------- */

enum Screen { SC_SETPIN, SC_LOCK, SC_LIST, SC_ACTIONS, SC_REVEAL, SC_ADD,
              SC_SETTINGS, SC_TOAST };
Screen screen = SC_LOCK;
Screen toastReturn = SC_LIST;

// smoothed animation state
float carousel   = 0;   // eases toward selectedIndex (horizontal card slide)
float pillY      = 0;   // eases toward the selected menu row
float shake      = 0;   // decays to 0; nonzero = wrong-PIN wiggle
uint32_t lastActivity = 0;

int  selectedIndex = 0;     // which vault entry
int  actionIndex   = 0;     // which action in the SC_ACTIONS menu
int  settingsIndex = 0;     // which row in the settings menu
bool changingPin   = false; // true = the PIN screen is setting a NEW pin, not unlocking
int  pinDigits[PIN_LENGTH]; // digits being entered
int  pinCursor = 0;
int  pinPass   = 0;         // first-run needs two matching passes
int  pinFirst[PIN_LENGTH];

String toastText;
uint32_t toastUntil = 0;

static void bumpActivity() { lastActivity = millis(); }

static void toast(const String& t, uint32_t ms, Screen back) {
  toastText = t; toastUntil = millis() + ms; toastReturn = back; screen = SC_TOAST;
}

// approach `target` by a fraction each frame — the whole animation system
static float ease(float cur, float target, float k = 0.22f) {
  float d = target - cur;
  if (fabs(d) < 0.001f) return target;
  return cur + d * k;
}

// draw text clipped to the panel, scrolling horizontally if it's too wide
static void drawMarquee(const char* txt, int x, int y, int w, uint32_t now) {
  int tw = oled.getStrWidth(txt);
  if (tw <= w) { oled.drawStr(x, y, txt); return; }
  int span   = tw + 20;                       // gap before it loops
  int offset = (now / 40) % span;
  oled.setClipWindow(x, 0, x + w, 32);
  oled.drawStr(x - offset, y, txt);
  oled.drawStr(x - offset + span, y, txt);
  oled.setMaxClipWindow();
}

// ---- individual screens -----------------------------------------------------

static void drawPinScreen(const char* title, uint32_t now) {
  oled.setFont(u8g2_font_5x8_tf);
  int tw = oled.getStrWidth(title);
  oled.drawStr((128 - tw) / 2, 8, title);

  // four rounded slots that fill as you enter digits
  int slotW = 20, gap = 6, total = PIN_LENGTH * slotW + (PIN_LENGTH - 1) * gap;
  int x0 = (128 - total) / 2 + (int)shake;
  oled.setFont(u8g2_font_7x14B_tf);
  for (int i = 0; i < PIN_LENGTH; i++) {
    int x = x0 + i * (slotW + gap);
    oled.drawRFrame(x, 14, slotW, 16, 4);
    if (i < pinCursor) {
      char d[2] = { (char)('0' + pinDigits[i]), 0 };
      oled.drawStr(x + (slotW - 7) / 2, 26, d);        // already-entered
    } else if (i == pinCursor) {
      char d[2] = { (char)('0' + pinDigits[i]), 0 };
      oled.drawRBox(x, 14, slotW, 16, 4);              // active slot: inverted
      oled.setDrawColor(0);
      oled.drawStr(x + (slotW - 7) / 2, 26, d);
      oled.setDrawColor(1);
    }
  }
}

// Flipper-ish status bar: name on the left, a lock glyph + entry count on the
// right. Lives in the top 9px; everything else draws below it.
static void drawStatusBar(const char* title) {
  oled.setFont(u8g2_font_4x6_tf);
  oled.drawStr(2, 6, title);
  // right side: little closed-lock + "n/total"
  oled.drawXBMP(96, 0, ic_lock_small_width, ic_lock_small_height, ic_lock_small_bits);
  if (!vault.empty() && selectedIndex < (int)vault.size()) {
    char c[12];
    snprintf(c, sizeof(c), "%d/%d", selectedIndex + 1, (int)vault.size());
    oled.setFont(u8g2_font_4x6_tf);
    oled.drawStr(108, 6, c);
  }
  oled.drawHLine(0, 8, 128);
}

// each entry gets an icon based on the first letter of its label, so the
// carousel doesn't look like the same key stamped over and over. Purely
// cosmetic — cycles through the glyph set.
static const unsigned char* iconForEntry(int i) {
  switch (i % 4) {
    case 0: return ic_key_bits;
    case 1: return ic_lock_small_bits;
    case 2: return ic_user_bits;
    default: return ic_settings_bits;
  }
}
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
void loop() {
  uint32_t now = millis();
  buttonsUpdate();
  serialPump();

  // auto-lock on idle (only once we're actually in; 0 = never)
  if (unlocked && screen != SC_ADD && screen != SC_SETPIN && idleLockMs > 0 &&
      now - lastActivity > idleLockMs) {
    lockDevice();
  }

  // route input to the active screen
  switch (screen) {
    case SC_SETPIN:
    case SC_LOCK:      handlePinInput(); break;
    case SC_LIST:      handleList();     break;
    case SC_ACTIONS:   handleActions();  break;
    case SC_REVEAL:    handleReveal();   break;
    case SC_ADD:       handleAdd();      break;
    case SC_SETTINGS:  handleSettings(); break;
    case SC_TOAST:     if (now > toastUntil) screen = toastReturn; break;
  }

  // advance animations (this is the whole "liquid" trick — nothing fancy)
  carousel = ease(carousel, selectedIndex, 0.25f);
  if (shake > 0.05f) shake = -shake * 0.7f;   // ring down toward zero
  else shake = 0;

  // render
  oled.clearBuffer();
  switch (screen) {
    case SC_SETPIN:
      drawPinScreen(changingPin ? (pinPass == 0 ? "New PIN" : "Confirm new")
                                : (pinPass == 0 ? "Set PIN" : "Confirm PIN"), now);
      break;
    case SC_LOCK:     drawPinScreen("Enter PIN", now); break;
    case SC_LIST:     drawList(now);     break;
    case SC_ACTIONS:  drawActions(now);  break;
    case SC_REVEAL:   drawReveal(now);   break;
    case SC_ADD:      drawAdd(now);      break;
    case SC_SETTINGS: drawSettings(now); break;
    case SC_TOAST:    drawToast(now);    break;
  }
  // unsaved-changes dot, top-right
  if (unlocked && vaultDirty && screen == SC_LIST) oled.drawDisc(124, 3, 1);
  oled.sendBuffer();

  delay(8);   // ~120 fps cap; keeps the eases smooth without pegging the CPU
}

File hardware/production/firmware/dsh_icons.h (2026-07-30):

/* ============================================================================
 *  dsh_icons.h  —  pixel art for DSH-AEGIS
 *  Hand-drawn XBM glyphs (LSB-first) for u8g2's drawXBMP().
 *
 *  logo_lock (26x23)  boot splash padlock, redrawn from Pratik's original art
 *  ic_key    (16x16)  "type password"
 *  ic_user   (16x16)  "type username + password"
 *  ic_eye    (16x16)  "reveal"
 *  ic_trash  (16x16)  "delete"
 *  ic_plus   (16x16)  "add entry"
 *  ic_lock_small (16x16)  vault / entry marker
 *  ic_settings   (16x16)  settings
 *
 *  Each entry gives a fresh entry a matching icon on the carousel. Draw with:
 *      u8g2.drawXBMP(x, y, ic_key_width, ic_key_height, ic_key_bits);
 * ========================================================================== */

#ifndef DSH_ICONS_H
#define DSH_ICONS_H

#ifndef U8G2_PROGMEM
#define U8G2_PROGMEM
#endif

#define logo_lock_width 26
#define logo_lock_height 23
static const unsigned char logo_lock_bits[] U8G2_PROGMEM = {
  0x00,0x00,0x00,0x00,0x00,0x00,0x00,0x00,0x00,0x78,0x00,0x00,0x00,0xFE,0x01,0x00,
  0x00,0x03,0x03,0x00,0x80,0x01,0x06,0x00,0x80,0x01,0x06,0x00,0xC0,0x00,0x0C,0x00,
  0xC0,0x00,0x0C,0x00,0xC0,0x00,0x0C,0x00,0xF0,0xFF,0x3F,0x00,0xF0,0xFF,0x3F,0x00,
  0xF0,0xFF,0x3F,0x00,0xF0,0x00,0x0F,0x00,0xF0,0x3C,0x0F,0x00,0xF0,0x3C,0x0F,0x00,
  0xF0,0x3C,0x0F,0x00,0xF0,0x3C,0x0F,0x00,0xF0,0x00,0x0F,0x00,0xF0,0xFF,0x3F,0x00,
  0xF0,0xFF,0x3F,0x00,0xF0,0xFF,0x3F,0x00,0x00,0x00,0x00,0x00,
};

#define ic_key_width 16
#define ic_key_height 16
static const unsigned char ic_key_bits[] U8G2_PROGMEM = {
  0x00,0x00,0xF0,0x03,0x18,0x06,0x0C,0x0C,0x0C,0x0C,0x0C,0x0C,0x18,0x06,0xF0,0x03,
  0xC0,0x00,0xC0,0x00,0xC0,0x03,0xC0,0x00,0xC0,0x03,0xC0,0x00,0xC0,0x01,0x00,0x00,
};

#define ic_user_width 16
#define ic_user_height 16
static const unsigned char ic_user_bits[] U8G2_PROGMEM = {
  0x00,0x00,0xC0,0x03,0x60,0x06,0x60,0x06,0x60,0x06,0xC0,0x03,0x00,0x00,0xF0,0x0F,
  0x0C,0x30,0x06,0x60,0x03,0xC0,0x03,0xC0,0x03,0xC0,0x00,0x00,0x00,0x00,0x00,0x00,
};

#define ic_eye_width 16
#define ic_eye_height 16
static const unsigned char ic_eye_bits[] U8G2_PROGMEM = {
  0x00,0x00,0x00,0x00,0x00,0x00,0xF0,0x03,0x0C,0x0C,0xE6,0x19,0xF3,0x33,0xF3,0x33,
  0xE6,0x19,0x0C,0x0C,0xF0,0x03,0x00,0x00,0x00,0x00,0x00,0x00,0x00,0x00,0x00,0x00,
};

#define ic_trash_width 16
#define ic_trash_height 16
static const unsigned char ic_trash_bits[] U8G2_PROGMEM = {
  0x00,0x00,0xF0,0x03,0xFC,0x3F,0x00,0x00,0xFE,0x1F,0xB6,0x0D,0xB6,0x0D,0xB6,0x0D,
  0xB6,0x0D,0xB6,0x0D,0xB6,0x0D,0xFE,0x1F,0x00,0x00,0x00,0x00,0x00,0x00,0x00,0x00,
};

#define ic_plus_width 16
#define ic_plus_height 16
static const unsigned char ic_plus_bits[] U8G2_PROGMEM = {
  0x00,0x00,0x00,0x00,0xC0,0x00,0xC0,0x00,0xC0,0x00,0xC0,0x00,0xFC,0x0F,0xFC,0x0F,
  0xC0,0x00,0xC0,0x00,0xC0,0x00,0xC0,0x00,0x00,0x00,0x00,0x00,0x00,0x00,0x00,0x00,
};

#define ic_lock_small_width 16
#define ic_lock_small_height 16
static const unsigned char ic_lock_small_bits[] U8G2_PROGMEM = {
  0x00,0x00,0xC0,0x03,0x60,0x06,0x60,0x06,0xF0,0x0F,0xF0,0x0F,0x30,0x0C,0xB0,0x0D,
  0xB0,0x0D,0x30,0x0C,0xF0,0x0F,0x00,0x00,0x00,0x00,0x00,0x00,0x00,0x00,0x00,0x00,
};

#define ic_settings_width 16
#define ic_settings_height 16
static const unsigned char ic_settings_bits[] U8G2_PROGMEM = {
  0x00,0x00,0xC0,0x00,0xF0,0x03,0xD8,0x06,0xCC,0x0C,0xC6,0x18,0xE6,0x19,0xE6,0x19,
  0xC6,0x18,0xCC,0x0C,0xD8,0x06,0xF0,0x03,0xC0,0x00,0x00,0x00,0x00,0x00,0x00,0x00,
};
#endif // DSH_ICONS_H

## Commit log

2026-07-13 add KiCad schematic, PCB, and BOM
    [DSH-AEGIS.csv, DSH-AEGIS.kicad_pcb, DSH-AEGIS.kicad_sch]
2026-08-13 Initial commit: compact DSH-AEGIS hardware layout and files
    [.stl, DSH-AEGIS.csv, DSH-AEGIS.kicad_pcb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]
2026-08-13 Reorganize repository: move new compact layout into fresh hardware folder
    [DSH-AEGIS CASE VER 1.stl, DSH-AEGIS.csv, DSH-AEGIS.kicad_pcb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]
2026-08-13 Update README with firmware and hardware changes
    Added update notice about new files and PCB changes.
2026-08-29 build: package gerbers.zip in production folder and clean up nested files
    [DSH-AEGIS.csv, DSH-AEGIS.kicad_pcb, DSH-AEGIS.kicad_sch]
2026-08-29 chore: remove kicad lock files
2026-08-29 refactor: move 3D model zip and case STL to hardware/CAD
    [DSH-AEGIS CASE VER 1.stl]
2026-10-02 Reorganize repo structure and remove scratch files
    - Rename CODE/ to firmware/ (matches README)
    - Move KiCad project to hardware/pcb/, case models to hardware/cad/
    - Move DSH-AEGIS.wrl into hardware/cad/
    - Move journal.md and BOM.csv into docs/ (fix journal image links)
    - Delete test-cube scratch files (.stl, PLSDAWG/board/plswork.stl, tuffmangoblud.step, jswork.step)
    - Delete committed KiCad lock files and _restore_backup folder
    - Remove duplicate hardware/CAD/ copies
    - gitignore KiCad lock and restore artifacts
    Claude-Session: https://claude.ai/code/session_01HgQGXgi3YNGGKeMvPJRGat
    [.stl, BOM.csv, DSH-AEGIS CASE VER 1.stl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]
2026-10-02 Fix journal image links and extend gitignore
    Follow-up to repo reorg: these were left unstaged in the prior commit.
    - journal.md asset links now point to ../assets/
    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
2026-10-02 Move BOM.csv back to repo root (reviewer requirement)
    Reviewers (@panda, @inspirely4) require the hand-made BOM in root.
    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
    [BOM.csv]
2026-10-02 Add firmware copy to production folder (reviewer @HarmanD)
    Harman's spec: production folder should contain the CAD .step files
    and the firmware files. Firmware added here; .step pending re-upload
    of the full CAD (current zip is truncated).
    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
